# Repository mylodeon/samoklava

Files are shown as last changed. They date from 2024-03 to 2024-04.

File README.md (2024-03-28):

# samoklava
## An autogenerated split 36 key keyboard

## Disclaimer

This is an early experimental prototype. Please do not rely on the autogenerated files and double check them manually
before sending them off to a PCB fab. The author and other random strangers on the internet have been able to produce
working keyboard prototypes from this repo; this does not mean that everything will work every time.

The author(s) waive(s) responsibility for any damage or regulatory violations caused by using this software (see
license). Please consult your local regulations around radio frequencies and what's allowed for DIY projects in your
country.

left | right
-|-	
left | right

A 5x3 split keyboard with 3 thumb keys. There is nothing unique about the keyboard layout. It's inspired by Corne and
Kyria, and has the exact number of keys needed for the [Miryoku](https://github.com/manna-harbour/miryoku) layout.

The interesting thing about this keyboard is that it's a declarative design:
* Layout is declared using [Ergogen](https://github.com/mrzealot/ergogen/). New: no fork needed!
* The build system uses Ergogen to translate YAML to a KiCad PCB and plate files for FR-4 fab or laser cutting
* uses [kicad-automation-scripts](https://github.com/productize/kicad-automation-scripts) and [FreeRouting](https://github.com/freerouting/freerouting) to **automatically route the traces on the PCB**
* uses [KiKit](https://github.com/yaqwsx/KiKit) to render PCB previews (see top of this file) and production-ready **Gerber files**

## Features

* A slider switch for battery for wireless Promicro clones (tested with nice!nano); the slider can be
  shorted with a jumper if `CONFIG_ZMK_SLEEP` is preferred.
* Wired operation with QMK should be possible but is not tested; TRRS footprints are included and routed. The pinout is
  identical with a five-column Corne sans the RGBLEDs.
* Reset switches are easily accessible. The footprints used are the same as on the Corne.

## How to

If you would like to modify this:
* fork it
* change `config.yaml` to your liking
* push your changes; the `build.yml` GitHub Workflow will pick it up, autoroute and generate Gerbers, all in a zip file.
  See https://github.com/soundmonster/samoklava/actions
* or:
  * make sure to have Docker CLI and NodeJS installed
  * run `make setup clean all`
  * check the `output` folder for KiCad PCBs and Gerbers

See the [workflow](.github/workflows/build.yml) or the [Makefile](Makefile) for more details.
See [my ZMK config](https://github.com/soundmonster/samoklava-zmk-config) for a suggested keymap.

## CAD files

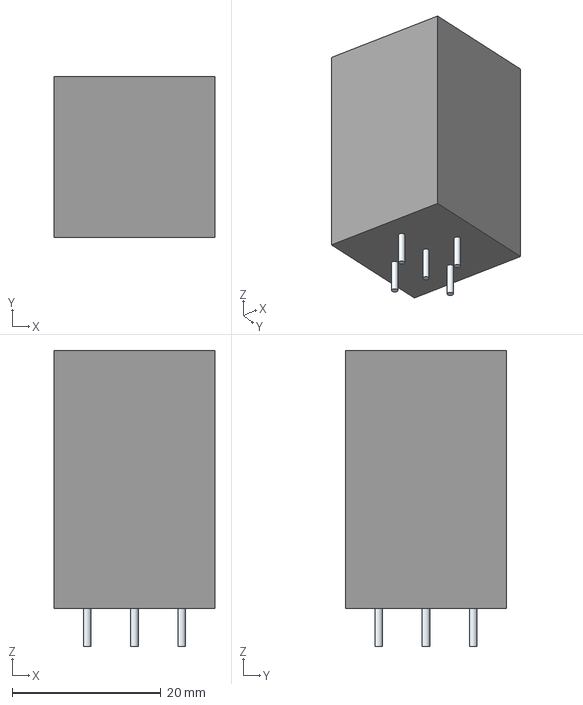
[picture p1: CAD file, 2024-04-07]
footprints/3d/04A-K01.stp
21.6 x 21.6 x 39.8 mm
Leads

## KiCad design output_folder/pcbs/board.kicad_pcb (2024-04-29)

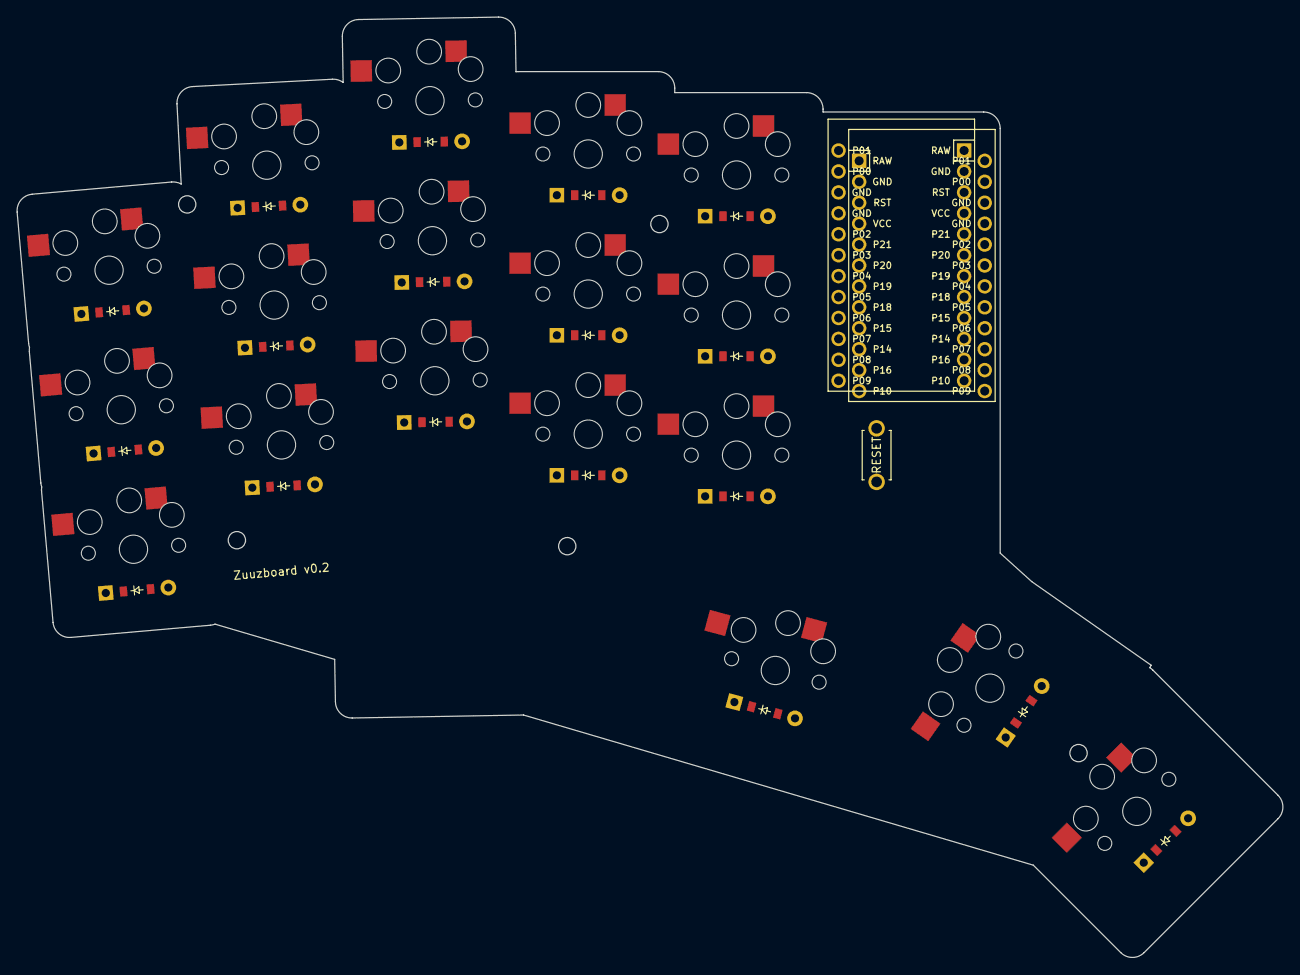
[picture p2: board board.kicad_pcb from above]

Board: 2 copper layers, 153.6 x 114.1 mm, 39 parts (0 on the bottom side), 40 nets, no tracks yet.

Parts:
B1: ResetSW
D1, D2, D3, D4, D5, D6, D7, D8, D9, D10, D11, D12, D13, D14, D15, D16, D17, D18: ComboDiode
MCU1, MCU2: ProMicro
S1, S2, S3, S4, S5, S6, S7, S8, S9, S10, S11, S12, S13, S14, S15, S16, S17, S18: PG1350

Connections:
GND: B1.2, MCU1.2, MCU1.15, MCU1.16, MCU2.2, MCU2.15, MCU2.16
P0: MCU1.14, MCU2.14
P1: MCU1.13, MCU2.13
P2: MCU1.17, MCU2.17
P3: MCU1.18, MCU2.18
P7: MCU1.22, MCU2.22
P8: MCU1.23, MCU2.23
P9: MCU1.24, MCU2.24
P10: MCU1.12, MCU2.12
P21: MCU1.5, MCU2.5
RAW: MCU1.1, MCU2.1
RST: B1.1, MCU1.3, MCU2.3
VCC: MCU1.4, MCU2.4
col_index: MCU1.20, S10.2, S11.2, S12.2, S17.2
col_inner: MCU1.19, S13.2, S14.2, S15.2, S18.2
col_middle: MCU1.21, S7.2, S8.2, S9.2, S16.2
col_pinky: MCU1.6, S1.2, S2.2, S3.2
col_ring: MCU1.7, S4.2, S5.2, S6.2
far_thumb: D18.2, S18.1
home_thumb: D17.2, S17.1
index_bottom: D10.2, S10.1
index_home: D11.2, S11.1
index_top: D12.2, S12.1
inner_bottom: D13.2, S13.1
inner_home: D14.2, S14.1
inner_top: D15.2, S15.1
middle_bottom: D7.2, S7.1
middle_home: D8.2, S8.1
middle_top: D9.2, S9.1
near_thumb: D16.2, S16.1
pinky_bottom: D1.2, S1.1
pinky_home: D2.2, S2.1
pinky_top: D3.2, S3.1
ring_bottom: D4.2, S4.1
ring_home: D5.2, S5.1
ring_top: D6.2, S6.1
row_bottom: D1.1, D4.1, D7.1, D10.1, D13.1, MCU1.11
row_home: D2.1, D5.1, D8.1, D11.1, D14.1, MCU1.9
row_thumb: D16.1, D17.1, D18.1, MCU1.8
row_top: D3.1, D6.1, D9.1, D12.1, D15.1, MCU1.10

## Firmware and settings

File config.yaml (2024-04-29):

meta:
  engine: 4.0.4
  name: Zuuzboard
  version: 0.4
  author: Deon
  url: https://github.com/soundmonster/samoklava
units:
  kx: cx
  ky: cy
  px: 2
  py: 2
points:
  key:
    footprints:
      choc_hotswap:
        type: combochoc
        params:
          hotswap: true
          reverse: true
          keycaps: true
        nets:
          from: =column_net
          to: =row_net
          to2: =key_net
  zones:
    matrix:
      key.padding: ky
      columns:
        pinky:
          key:
            stagger: 0 ky
            spread: kx
            splay: 12
          rows:
            bottom:
              column_net: col1
              key_net: c1r3
            home:
              column_net: col1
              key_net: c1r2
            top:
              column_net: col1
              key_net: c1r1
        ring:
          key:
            stagger: 0.65 ky
            spread: 19
            splay: -6
          rows:
            bottom:
              column_net: col2
              key_net: c2r3
            home:
              column_net: col2
              key_net: c2r2
            top:
              column_net: col2
              bind: 55
              key_net: c2r1
        middle:
          key:
            stagger: 0.4 ky
            spread: 19
            splay: -4
          rows:
            bottom:
              column_net: col3
              key_net: c3r3
            home:
              column_net: col3
              key_net: c3r2
            top:
              column_net: col3
              key_net: c3r1
        index:
          key:
            stagger: -0.4 ky
            spread: 18.5
            splay: -2
          rows:
            bottom:
              column_net: col4
              key_net: c4r3
            home:
              column_net: col4
              key_net: c4r2
            top:
              column_net: col4
              key_net: c4r1
        inner:
          key:
            stagger: -0.15 ky
            spread: kx
          rows:
            bottom:
              column_net: col5
              key_net: c5r3
            home:
              column_net: col5
              key_net: c5r2
            top:
              column_net: col5
              key_net: c5r1
      rows:
        bottom:
          row_net: row3
        home:
          row_net: row2
        top:
          row_net: row1
    thumbfan:
      anchor:
        ref: matrix_inner_bottom
        shift: [-0.35 kx, -1.1 ky]
      columns:
        near:
          key:
            spread: kx
            splay: -29
            rotate: 90
            origin: [-1 kx, -1 ky]
            column_net: col5
            key_net: c5r4
        home:
          key:
            spread: kx
            splay: -8
            rotate: 90
            origin: [-0.5 kx, -0.85 ky]
            column_net: col4
            key_net: c4r4
        far:
          key:
            spread: kx
            splay: -8
            rotate: 90
            origin: [-0.6 kx, -0.85 ky]
            column_net: col3
            key_net: c3r4
      rows:
        thumb:
          row_net: row4
#    thumbfantest1:
#      anchor:
#        ref: matrix_inner_bottom
#        shift: [-0.6 kx, -1.8 ky]
#      columns:
#        home:
#          key:
#            spread: kx
#            splay: -35
#            rotate: 90
#            origin: [0.55 kx, -3.55 ky]
#            column_net: P8
#        far:
#          key:
#            spread: kx
#            splay: -10
#            rotate: 90
#            origin: [-0.55 kx, -1.2 ky]
#            column_net: P9
#      rows:
#        thumb:
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

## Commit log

2024-03-28 Remove another diode
2024-03-28 Remove choc hotswap footprint
2024-03-28 Remove diode
2024-04-07 Switch to Heawood Graph
2024-04-07 Update board size
2024-04-07 Fix top plate
2024-04-14 Add diodes
2024-04-14 Reduce board for autorouting
2024-04-14 PUT BACK DIODES
2024-04-14 Simpler footprint
2024-04-15 v.0.3 Fix routing thumbs
    [config.yaml]
2024-04-28 Add rotary encoder
2024-04-28 Rev Board
2024-04-28 Change board
2024-04-29 Zuuz v0.004 board
    [board.kicad_pcb, bottom_plate.kicad_pcb, top_plate.kicad_pcb]
